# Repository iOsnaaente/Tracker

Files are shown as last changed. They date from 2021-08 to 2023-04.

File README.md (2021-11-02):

# Tracker
Criação de um supervisório para controle de movimentação de um gerador solar do tipo rastreador do sol - Tracker

# Requerimentos
pip install -r requirements.txt

# Dear PyGui 
Software criado sobre a GUI DearPygui - https://github.com/hoffstadt/DearPyGui

# Log 

Protótipo de criação de um rastreador solar - Tracker
    
    Firmware utilizado em um Raspberry pi Pico para controle
    de motores de passo que realizam o rastreamento solar
    garantindo mais geração elétrica a partir de painéis
    fotovoltáicos.

    Versão 0.9.2::
        >>> Código AS5043A para encoder Magnético
        >>> Nova tentativa de rastreamento da posição dos motores

    Versão 0.9.1::
        >>> Processamento dos dados do acelerometro
        >>> Valores obtidos inconclusivos para a finalidade
        >>> Acelerometro não será usado 
    
    Versão 0.9.0::
        >>> Criação do arquivo Acell.py para os dados do acelerometro
        >>> Teste do acelerometro
        >>> Criação das funções de acionamento dos motores via relé 

    Versão 0.8.1::
        >>> Adaptação da placa de desenvolvimento::
            >>> Acrescimo do relé de acionamento dos motores 
    
    Versão 0.8.0::
        >>> Correção da comunicação serial.
        >>> Criação de mais variáveis de estado
        
    Versão  0.7.0::
        >>> Criação do módulo Timanager. Junção de Timer e Manager
            Realiza todo controle de passagem de tempo e movimento
            decorrente desse periodo.
    
    Versão 0.6.1::
        >>> Correção do movimento de retorno do Tracker.
            >>>Segundo teste de fogo::
                >>> Controle de retorno OK
                
    Versão 0.6.0::
        >>> Movimentação acelerada do movimento real de rastreio.
            >>>Primeiro teste de fogo::
                >>> Movimentação OK 
                >>> Dados precisos OK
                >>> Controle de retorno FAIL
    
    Versão 0.55.0::
        >>> Extinção do uso de threads para os Levers.
        >>> Extinção do uso de threads para a Serial.
        
    Versão  0.5.0::
        >>> Levers. Criação da Classe Levers para controle manual dos
            motores via alavancas presas à placa de desenvolvimento.
            Evitando poluição de código.
            
    Versão  0.4.0::
        >>> Const. Evitando poluição do escopo principal (main),
            separou-se as constantes em outro file.py chamado Const
        >>> FileStatements. Criação de um file.py FileStatements
            que guarda as funções de escrita Flash do RasPico.
            
    Versão  0.3.0::
        >>> Serial comunication. Ponta pé inicial da comunicação serial
            utilizando structs pack e unpack. Funcional, mas incompleto.
            
    Versão  0.23.0::
        >>> Finalização da Classe StepMotors. Adição dos nanoSteps que
            guardam decimais do movimento dos motores.
            StepMotors agora esta mais organizado e limpo.
            Funcionando 100% porém falta documentar.
        >>> Criação da função get_twilights() dentro de SunPosition.
            Função responsável por pegar os horários de crepusculos do dia.
            
    Versão  0.21.0::
        >>> Correção da classe StepMotors. Separação da classe Motors
            em duas classes distintas. Motors e Motor ( pai e filho).
        >>> Correção no código do DS3231.
        >>> Documentação do código do DS3231. Agora esta 100%.
        
    Versão  0.2.0::
        >>> Criação da interface StepMotors para fazer o controle dos
            motores de passo.
        >>> Criação da interface DS3231. Faltam ajustes.
        >>> Finalização do código SunPosition de rastreio solar. Já funciona.
        
    Versão  0.1.0::
        >>> Correções no código SunPosition de rastreio solar. Definição
            final de como será feito a computação das posições de azimute
            e zenite( altitude ) sem o uso de classes.
            >>> Função Compute() realiza todos os cálculos.
            
    Versão 0.01.0::
        >>> Estruturação do primeiro modelo funcional.
        >>> Definição de todo o escopo do Firmware.
            >>> Rastreio solar - SunPosition
            >>> Contagem da hora - DS3231
            >>> Controle dos motores - StepMotors
            
    Versão 0.0.10::
        >>> Migração do código em C ( Arduino ) para Python 
     
"""

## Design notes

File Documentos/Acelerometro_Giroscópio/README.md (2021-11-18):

# Sensor Magnetômetro 3 Eixos - GY-271

O Sensor Magnetômetro 3 Eixos Gy-271 mede o campo magnético e funciona como uma Bússola Digital, podendo ser usado por exemplo com o Arduino para indicar o norte geográfico da Terra.

[b] Durante um periodo de 24h a bussola gira 360º em sentido norte, provando que a Terra gira em um periodo de aproximadamente 24h :D 

Sensor adquirido em https://www.eletrogate.com/sensor-magnetometro-3-eixos-gy-271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 

Protocolo de comunicação I2C 

Necessita da biblioteca QMC5883LCompass anexa em ./utils
Criada por [MPrograms](https://github.com/mprograms/QMC5883LCompass/) Página git do projeto [Github Project Page](https://github.com/mprograms/QMC5883LCompass/)

Para mais informações ler o README da biblioteca anexa 

## Ploter.py 
O repositório GY-271 com os códigos arduino possuem também um arquivo Ploter.py que nada mais é do que um plotador dos dados recebidos via Serial. 

Para rodar o ploter, há a necessidade de se ter instala a biblioteca DearPyGui na sua versão 0.8.4 disponível em requirements.txt 

# MMA845x

Sensor adquirido em https://www.baudaeletronica.com.br/acelerometro-3-eixos-mma8452.html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

Protocolo de comunicação I2C 

Necessita da biblioteca SFE_MMA8452Q anexa em ./utils
Biblioteca criada por: [MPrograms](Jim Lindblom @ SparkFun Electronics) 
Disponível em: [Github Project Page](https://github.com/sparkfun/MMA8452_Accelerometer)

## Ploter.py 
O repositório GY-271 com os códigos arduino possuem também um arquivo Ploter.py que nada mais é do que um plotador dos dados recebidos via Serial. 

Para rodar o ploter, há a necessidade de se ter instala a biblioteca DearPyGui na sua versão 0.8.4 disponível em requirements.txt

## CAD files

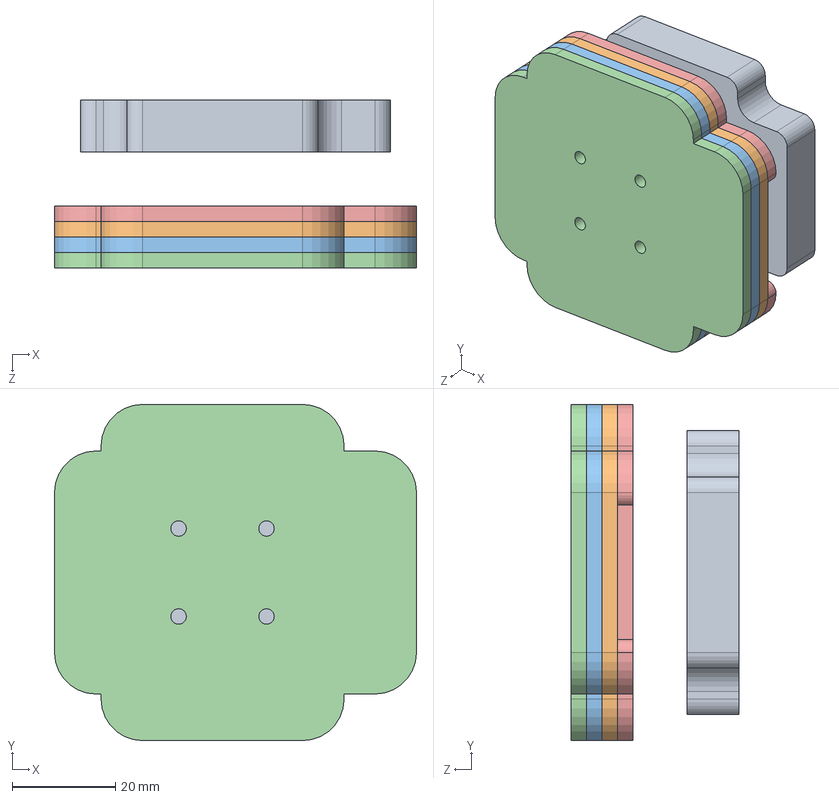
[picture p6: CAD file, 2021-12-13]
3D/SuporteSensor/Montagem3.SLDASM
70.0 x 65.0 x 32.4 mm
Braçadeira1
Base_sensor^Montagem3
Base
BraçadeiraFios
CentralizadorImã

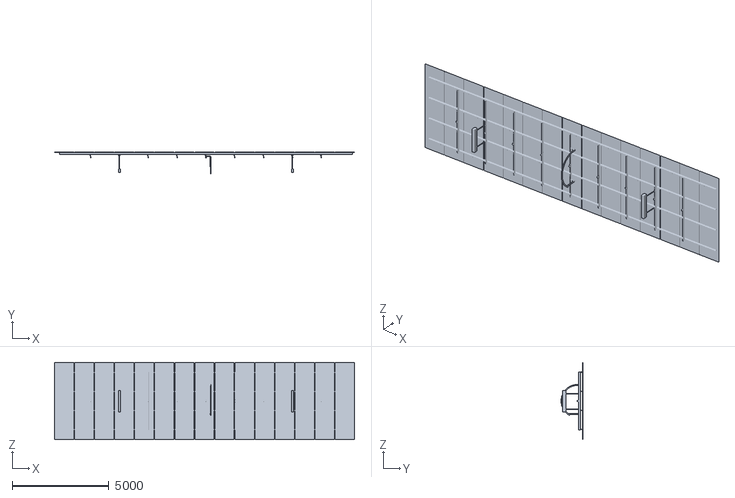
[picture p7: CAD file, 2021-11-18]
3D/Elevação.STL
15500.0 x 1131.9 x 4000.0

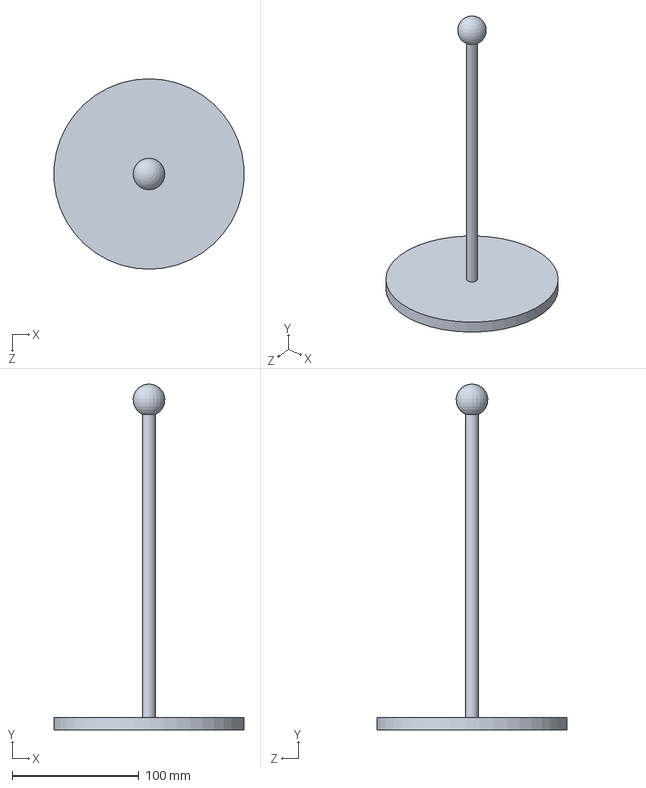
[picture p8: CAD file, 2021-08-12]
3D/models/GIR_PAINEL.SLDPRT
149.6 x 272.5 x 150.0 mm

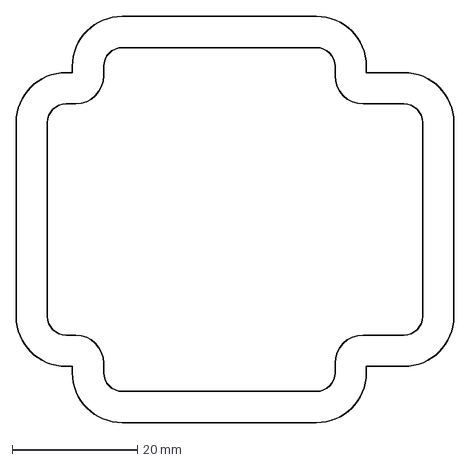
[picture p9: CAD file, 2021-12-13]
3D/SuporteSensor/Braçadeira_x2.DXF
70.0 x 65.0 mm

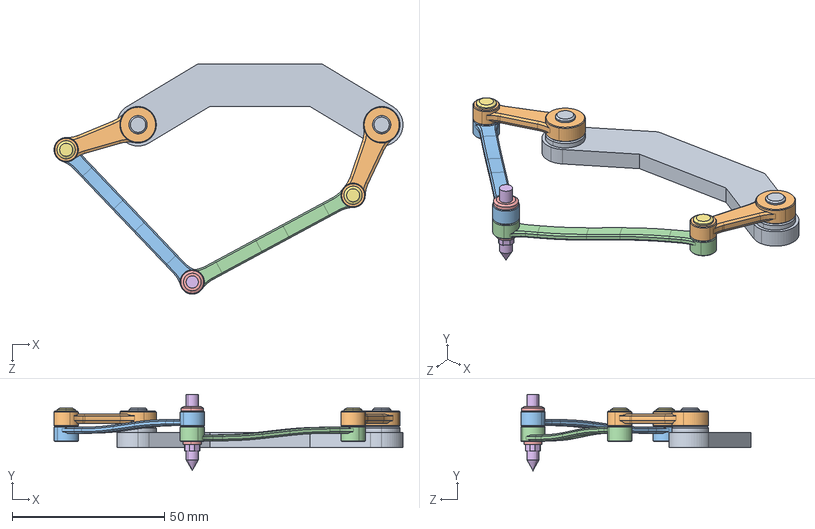
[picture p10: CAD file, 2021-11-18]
Interface/utils/ico/5 Linkages Mechanism.STEP
114.6 x 25.0 x 75.6 mm
Base
Link-01 x 2
Link-02
Link-02_Reverse
Connector
Pen
Pin x 2

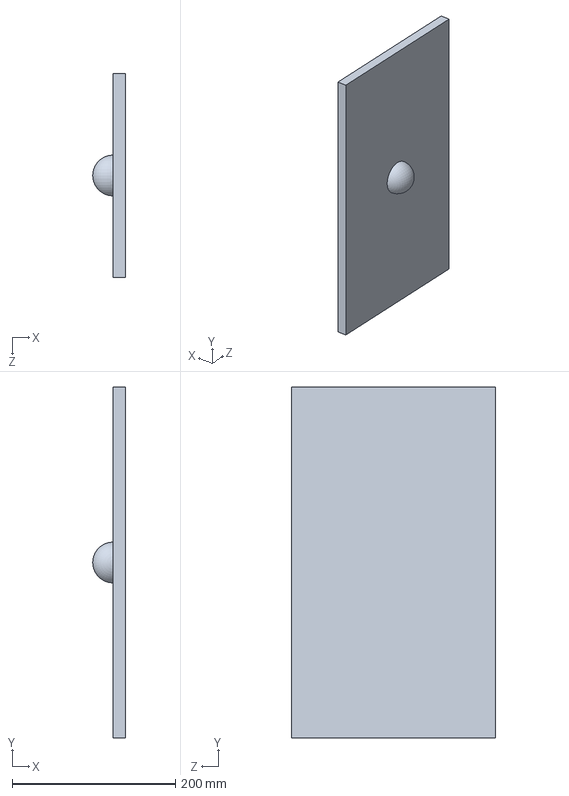
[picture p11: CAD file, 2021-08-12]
3D/models/ELE_PAINEL.SLDPRT
40.0 x 430.0 x 250.0 mm

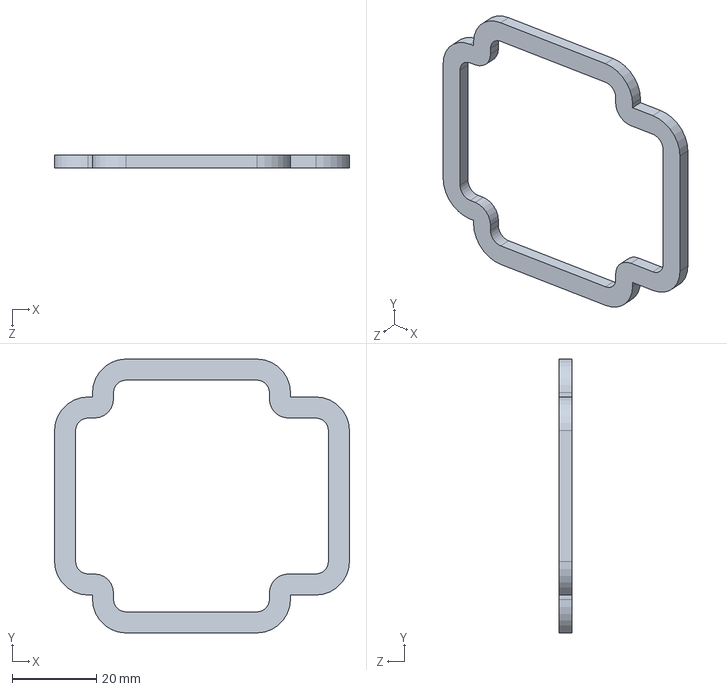
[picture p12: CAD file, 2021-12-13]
3D/SuporteSensor/Braçadeira1.sldprt
70.0 x 65.0 x 3.00 mm

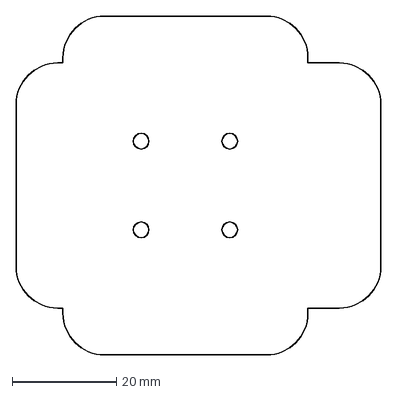
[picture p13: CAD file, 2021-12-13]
3D/SuporteSensor/Base_x2.DXF
70.0 x 65.0 mm

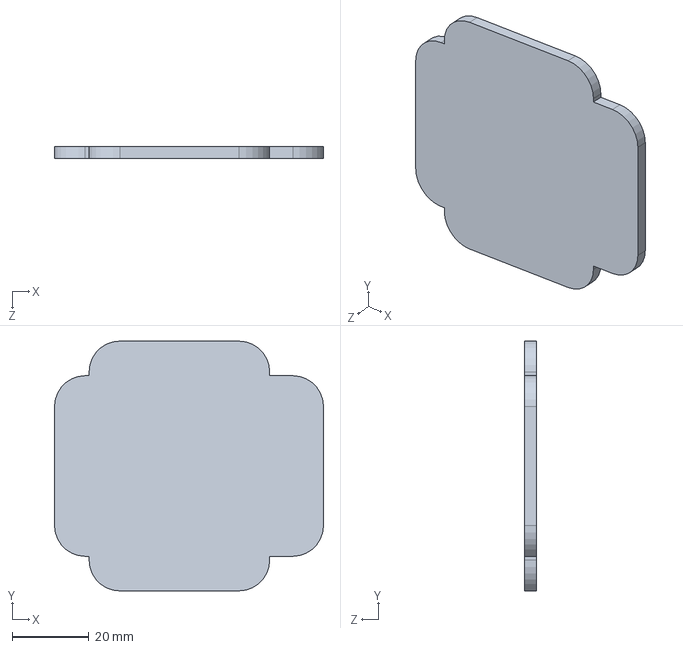
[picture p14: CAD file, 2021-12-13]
3D/SuporteSensor/Base.sldprt
70.0 x 65.0 x 3.00 mm

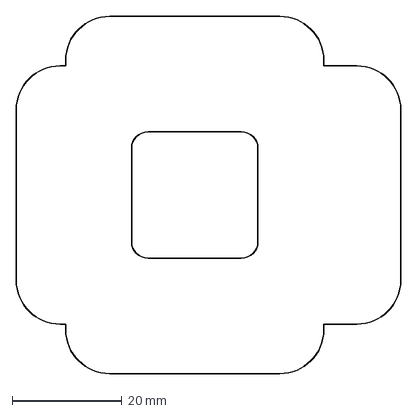
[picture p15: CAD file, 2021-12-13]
3D/SuporteSensor/BaseSensor_x2.DXF
70.0 x 65.0 mm

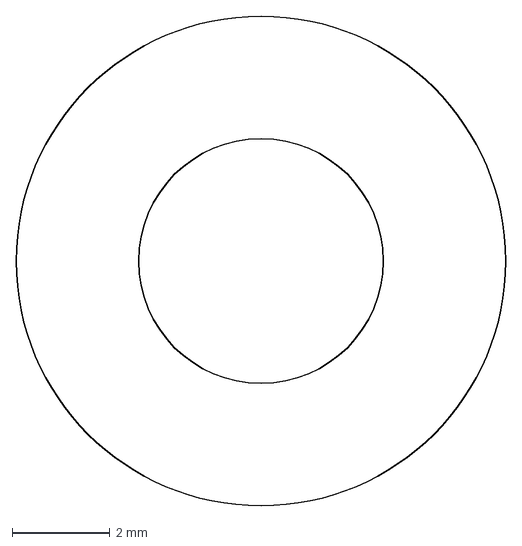
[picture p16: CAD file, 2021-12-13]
3D/SuporteSensor/CentralizadorImã_x3.DXF
10.0 x 10.0 mm

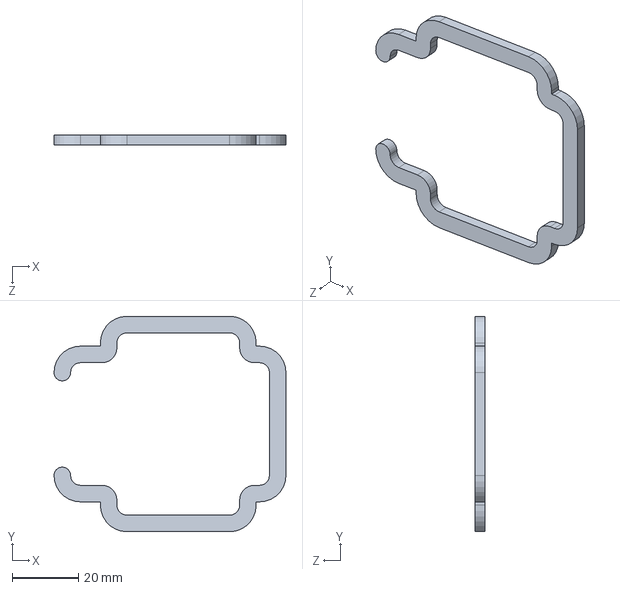
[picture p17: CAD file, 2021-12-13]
3D/SuporteSensor/BraçadeiraFios.sldprt
70.0 x 65.0 x 3.00 mm

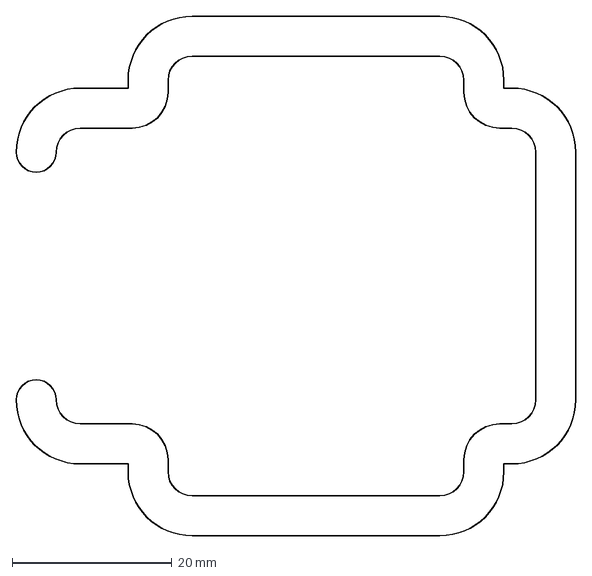
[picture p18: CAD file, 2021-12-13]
3D/SuporteSensor/BraçadeiraFios_x2.DXF
70.0 x 65.0 mm

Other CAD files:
3D/SuporteSensor/Tampa_Top.sldprt
3D/SuporteSensor/CentralizadorImã.sldprt
3D/SuporteSensor/Corpo_Body.sldprt
3D/SuporteSensor/Tampa_Button.sldprt
3D/models/ELE_PAINEL.STL
3D/models/ELE_PAINEL.obj
3D/models/GIR_PAINEL.STL
3D/models/GIR_PAINEL.obj

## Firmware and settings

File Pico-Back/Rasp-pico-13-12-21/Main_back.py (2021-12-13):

#!/usr/bin/env python
# -*- coding: utf-8 -*-

from machine        import Pin, I2C

from Levers         import Lever_control
from Timanager      import Timemanager 
from StepMotors     import Motors
from DS3231         import DS3231
from Acell          import *
from SunPosition    import *
from FileStatements import *
from Const          import * 

import select 
import struct 
import time 
import sys
import gc

# INSTANCIAMENTO DOS PERIFÉRICOS 
MOTORS = Motors( STEP_GIR, DIR_GIR, STEP_ELE, DIR_ELE, ENABLE_MTS )
MOTORS.configure( MOTORS.GIR, pos = 0.0, step = 1.8, micro_step = 8, ratio = 1 )
MOTORS.configure( MOTORS.ELE, pos = 0.0, step = 1.8, micro_step = 8, ratio = 1 )
MOTORS.set_torque( True )

# Ativa os motores 
POWER_MOTORS_STATE = HIGH  
POWER_MOTORS = Pin( POWER, Pin.OUT )  
POWER_MOTORS.value( POWER_MOTORS_STATE ) 

LED_POWER = Pin(LED1_RED , Pin.OUT)

def turn_off_motors():
    POWER_MOTORS_STATE = LOW
    POWER_MOTORS.low( )
    LED_POWER.low( ) 
    
def turn_on_motors():
    POWER_MOTORS_STATE = HIGH
    POWER_MOTORS.high( )
    LED_POWER.high( ) 
    

# BOTÕES / ALAVANCAS PARA MOVER OS MOTORES
LEVERS = Lever_control( lever_pins_A = [BUTTON_GP,BUTTON_GM], lever_pins_B = [BUTTON_EP,BUTTON_EM], LED = [LED1_RED, LED1_BLUE]  )


# LEDS E LED BUILTIN DA PLACA PICO 
LED2_RED    = Pin(LED2_RED , Pin.OUT)
LED2_BLUE   = Pin(LED2_BLUE, Pin.OUT)
LED_BUILTIN = Pin( LED_BUILTIN, Pin.OUT ) 


# SERIAL CONFIGURAÇÕES 
BYTE_INIT = [b'I',b'N',b'I',b'T']  
count     = 0

# PINOS DO DS3231 
DS  = DS3231( 0, Pin( SDA_DS ), Pin( SCL_DS ), addrs = [0x68, 0x57] )

try:
    #MAG = QMC5883L( i2c_bus = I2C(1, Pin(18,Pin.OUT), Pin(19, Pin.OUT)), address=DFLT_ADDRESS, output_data_rate=ODR_200HZ, output_range=RNG_8G, oversampling_rate=OSR_512 ) 
    mag = I2C(1, sda=Pin(18,Pin.OUT), scl=Pin(19, Pin.OUT), freq = 100_000)
    print( mag, mag.scan() )
    a = mag.readfrom_mem( 13, 0x00, 2 )
    print( a ) 
    MAG = QMC5883L( mag ) 
except: 
    print("MAG not connected")

# CONTROLE DOS ANGULOS DO SOL 
timanager = Timemanager( DS, MOTORS )

# Garbage Collector Enable 
gc.enable()


# SETAR A HORA DO DS3231 
#DS.set_time( 21, 10, 21, 16, 47, 20  )


# ESTADO DE INICIALIZAÇÃO
STATE = WAKE_UP

autoEngine = True 
time_delay = 1 
count_mov  = 0 
last_time  = time.time() 

LIMIT = 50 
DATA_TRAIN = [] 

while True:
    # INICIALIZAÇÃO
    if STATE == WAKE_UP:
        print( "BOM DIA!!!") 
        
        #TIME = timanager.up_fake_time( up = True )
        TIME = DS.now() 
        
        timanager.start( TIME )
        
        STATE = AUTOMATIC_TRACKING
        
        if autoEngine: 
            turn_on_motors() 
        else:
            turn_off_motors()

    elif STATE == GET_DATA:
        LED_BUILTIN.toggle()
        levers_state = LEVERS.check_levers()
        if any(levers_state):
            if   levers_state[0]: timanager.move(  1,  0 )
            elif levers_state[1]: timanager.move( -1,  0 )
            if   levers_state[2]: timanager.move(  0,  1 )
            elif levers_state[3]: timanager.move(  0, -1 ) 
            count_mov += 1
            
            try:
                x,y,z = MAG.get_magnet_raw()
            except:
                print( 'Error. magnetico fora ')
                x,y,z = 0,0,0
                
            DATA = struct.pack('ffffff',count_mov,timanager.MOTORS.GIR_POS, timanager.MOTORS.ELE_POS, x, y, z) 
            DATA_TRAIN.append( DATA )
            
            if count_mov > 0:       
                with open('reg.txt', 'a') as f : 
                    f.write( b'{},\n'.format(DATA_TRAIN) )
                DATA_TRAIN = [] 


    # RASTREADOR 
    elif STATE == AUTOMATIC_TRACKING:
        #TIME = timanager.up_fake_time( )
        TIME = DS.now() 
        timanager.update( TIME )
        
        if timanager.get_altitude() > 0:
            LED2_BLUE.high()
            LED2_RED.low()            
        else:
            LED2_BLUE.low()
            LED2_RED.high()
            STATE = AUTOMATIC_BACKWARD 
    

    # RETORNO PARA O PONTO INICIAL DO DIA SEGUINTE 
    elif STATE == AUTOMATIC_BACKWARD:
        TIME[2] += 1
        if TIME[1] == 2: 
            if ANB(TIME[0]) :  DOM[1] = 29 
            else:              DOM[1] = 28 
        if TIME[2] > DOM[TIME[1]]:
            TIME[1] += 1
            TIME[2] = 1 
            if TIME[1] > 12: 
                TIME[0] += 1
                TIME[1] = 1 
            
        timanager.update( TIME )

        STATE = AUTOMATIC_SLEEPING
        continue 
    

    # ESPERA O NOVO DIA NASCER 
    elif STATE == AUTOMATIC_SLEEPING:
        TIME = DS.now() 
        if timanager.check_alt( TIME ):
            STATE = AUTOMATIC_TRACKING

    # INICIA O MODO DE OPEÇÃO ACELERADO ( DEMONSTRAÇÃO )
    elif STATE == MANUAL_DEMO:
        TIME = timanager.up_fake_time( up = True )
        timanager.update( TIME )
        timanager.print() 
    
    
    # CONTROLE MANUAL ATRAVÉS DOS LEVERS
    elif STATE == MANUAL_CONTROLING:
        levers_state = LEVERS.check_levers()
        if any(levers_state):
            if   levers_state[0]: timanager.move(  1,  0 )
            elif levers_state[1]: timanager.move( -1,  0 )
            if   levers_state[2]: timanager.move(  0,  1 )
            elif levers_state[3]: timanager.move(  0, -1 ) 
    

    # PARA O TRACKER
    elif STATE == MANUAL_STOPING:
        pass


    # VERIFICA SE RECEBEU ALGO DA SERIAL 
    while sys.stdin in select.select( [sys.stdin], [sys.stdout], [sys.stderr], 0 )[0]:  
        cmd = sys.stdin.buffer.read(1)
        if cmd == BYTE_INIT[count]:  count += 1
        else:                        count  = 0
 
        if count == 4:
            count = 0
            BYTE_ID  = sys.stdin.buffer.read(1)
            LED_BUILTIN.toggle()
            

            '''
            H -> Troca a hora
            M -> Move ambos motores
            m -> Move um dos motores
            S -> Para o tracker ( muda o estado )
            D -> Entra no modo Demo ( Demontração )
            C -> Para continuar o processo ( muda o estado ) 
            R -> Retorna para o inicio do dia
            O -> Muda para ativado os motores
            F -> Muda para desativado os motores 
            G -> Get data to conv net
            A -> Acelerometro medidas 
            '''
            
            
            if   BYTE_ID == b'H':
                confirm = sys.stdin.buffer.read(1)
                if confirm == b'O':
                    print('Recebido: {} para trocar a hora'.format(BYTE_ID))
                    year, month , day    = sys.stdin.buffer.read(3)
                    hour, minute, second = sys.stdin.buffer.read(3)
                    DS.set_time( year, month, day, hour, minute, second )
            
            
            elif BYTE_ID == b'M':
                confirm = sys.stdin.buffer.read(1)
                if confirm == b'O':
                    print('Recebido: {} para mover os dois motores'.format(BYTE_ID))
                    posG = struct.unpack( 'f', sys.stdin.buffer.read(4) )
                    posE = struct.unpack( 'f', sys.stdin.buffer.read(4) )
                    print(posG, posE, type(posG), type(posE))
                    timanager.move_to( POS = [ posG, posE ] )
                
                
            elif BYTE_ID == b'm':
                confirm = sys.stdin.buffer.read(1)
                if confirm == b'O':
                    print('Recebido: {} para mover somente um motor'.format(BYTE_ID))
                    motor_id = sys.stdin.buffer.read(1)
                    if motor_id == b'E':
                        posE = struct.unpack( 'f', sys.stdin.buffer.read(4) )
                        posG = [ float(s2f) for s2f in file_readlines( FILE_PATH, FILE_READ ) ][0]
                        timanager.move_to( POS = [ posG, posE ] )
                        print('POS E:', posE,' POS G:', posG, ' TYPE E:', type(posE),' TYPE G:',type(posG))

                    if motor_id == b'G':
                        posG = struct.unpack( 'f', sys.stdin.buffer.read(4) )
                        posE = [ float(s2f) for s2f in file_readlines( FILE_PATH, FILE_READ ) ][1]
                        timanager.move_to( POS = [ posG, posE ] )
                        print('POS E:', posE,' POS G:', posG, ' TYPE E:', type(posE),' TYPE G:',type(posG))
            
            
            elif BYTE_ID == b'S':
                confirm = sys.stdin.buffer.read(1)
                if confirm == b'O':
                    print('Recebido: {} para parar o processo'.format( BYTE_ID))
                    STATE = MANUAL_STOPING
            

            elif BYTE_ID == b'D':
                confirm = sys.stdin.buffer.read(1)
                if confirm == b'O':
                    print('Recebido: {} para iniciar o modo de demonstração do processo'.format( BYTE_ID))
                    STATE = MANUAL_DEMO
                    TIME = DS.now() 
                    timanager.update(TIME)
                    time_delay = 1 
            
            
            elif BYTE_ID == b'C':
                confirm = sys.stdin.buffer.read(1)
                if confirm == b'O':
                    print('Recebido: {} para continuar o processo'.format( BYTE_ID))
                    STATE = AUTOMATIC_TRACKING
                    timanager.update(TIME)
                    time_delay = 1 
                
                
            elif BYTE_ID == b'R':
                confirm = sys.stdin.buffer.read(1)
                if confirm == b'O':
                    print('Recebido: {} para retornar ao inicio do dia'.format( BYTE_ID))
                    TIME = DS.now()
                    TIME[3:6] = [0,0,0]
                    timanager.update(TIME)
            
            
            elif BYTE_ID == b'W':
                confirm = sys.stdin.buffer.read(1)
                if confirm == b'O':
                    print('Hello Tracker!!'.encode() )
            
            
            elif BYTE_ID == b'P':
                confirm = sys.stdin.buffer.read(1)
                if confirm == b'O':
                    timanager.print()
            
            elif BYTE_ID == b'O':
                confirm = sys.stdin.buffer.read(1)
                if confirm ==  b'O':
                    sys.stdout.write("Turn on the power motors".encode())
                    turn_on_motors()
            
            elif BYTE_ID == b'F':
                confirm = sys.stdin.buffer.read(1)
                if confirm == b'O':
                    sys.stdout.write("Turn off the power motors".encode())
                    turn_off_motors()
            
            elif BYTE_ID == b'G':
                confirm = sys.stdin.buffer.read(1)
                if confirm == b'O':
                    print('Aquisição de dados')
                    STATE = GET_DATA 
                    time_delay = 0.001
                    last_time = time.time()
                    count_mov = 0
            
            elif BYTE_ID == b'A':
                confirm = sys.stdin.buffer.read(1)
                if confirm == b'O':
                    try: 
                        print( MAG.get_magnet_raw() )
                    except:
                        try:
                            print( 'Magnetic sensor error: {}'.format(MAG.scan() ) )  
                        except:
                            print("Magnetic sensor not conected")
    #timanager.print()
    time.sleep(time_delay)
    
    # GARBAGE COLLECTOR 
    #gc.collect()

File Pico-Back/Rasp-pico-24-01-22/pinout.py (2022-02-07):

# VARIÁVEIS USADAS NAS GPIOs DO RASPICO 
STEP_GIR    = 0 
STEP_ELE    = 1 
STEP_GEN    = 2

DIR_GIR     = 3
DIR_ELE     = 4
DIR_GEN     = 5 

BUTTON_GP   = 6 
BUTTON_GM   = 7

BUTTON_EP   = 8
BUTTON_EM   = 9

LED1_RED    = 10
LED1_BLUE   = 11
LED2_RED    = 12
LED2_BLUE   = 13

ENABLE_MTS  = 14

POWER       = 15

SDA_DS      = 16 
SCL_DS      = 17
 
SDA_AS      = 18
SCL_AS      = 19 

UART_TX     = 20 
UART_RX     = 21

LED_BUILTIN = 25

# DATA E HORA 
UTC = -3 
DOM = [ 31, 28, 31, 30, 31, 30, 31, 31, 30, 31, 30, 31]
ANB = lambda year : True if (year%100 != 0 and year%4 == 0) or (year%100 == 0 and year%400 == 0) else False

# CONFIGURAÇÕES DE RASTREAMENTO 
LATITUDE    = -29.16530765942215
LONGITUDE   = -54.89831672609559 
TEMPERATURE =  298.5
PRESSURE    =  101.0

LOCALIZATION = [ LATITUDE, LONGITUDE, TEMPERATURE, PRESSURE ]


AUTOMATIC = 1
MANUAL    = 2
REMOTE    = 3
DEMO      = 4
IDLE      = 5

# MACRODEFINIÇÕES 
AUTOMATIC_SLEEPING =  3   # Dormindo esperando um novo dia começar 
AUTOMATIC_BACKWARD =  2   # Retorna para a posição inicial do novo dia
AUTOMATIC_TRACKING =  1   # Rastreia o sol em um dia normal 
WAKE_UP            =  0   # Opção de inicio. É chamado quando o Rasp liga
MANUAL_CONTROLING  = -1   # Ativa o controle por Levers 
MANUAL_STOPING     = -2   # Para o rastreio do tracker
MANUAL_DEMO        = -3   # Segue o sol de forma acelerada ( Demonstração ) 
GET_DATA           =  99 

LOW = 0
HIGH = 1 

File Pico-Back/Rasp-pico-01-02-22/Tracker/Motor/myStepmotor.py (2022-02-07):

from machine import Pin
from time    import sleep_ms
from rp2     import StateMachine 
from rp2     import asm_pio 
from rp2     import PIO

BACKWARD = False
FORWARD  = True

DISABLE = 1 
ENABLE  = 0

@asm_pio( set_init = PIO.OUT_LOW )
def move():
    label('init')
    pull( )
    mov( x, osr )
    label( 'step_m1' )
    set(pins, 1)             
    set(pins, 0)            
    jmp( x_dec, 'step_m1')  
    jmp( 'init' )

class Motor: 
    direction = FORWARD
    torque    = ENABLE
    position  = 0.0 
    ratio     = 1.0 
    step      = 1.8
    u_step    = 16 
    nano_step = 0.0
    name      = '' 

    # Para ter 30rpm durante 1 segundo
    rpm       = 0 
    pps       = 800  

    def __init__(self, STEP_PIN : int, DIRECTION_PIN : int, ENABLE_PIN : int, TORQUE : bool = False, FREQ : int = 2000, NUM_SM : int = 1 ) -> None:
        self.STEP_PIN       = Pin( STEP_PIN     , Pin.OUT ) 
        self.DIRECTION_PIN  = Pin( DIRECTION_PIN, Pin.OUT )
        self.ENABLE_PIN     = Pin( ENABLE_PIN   , Pin.OUT )

        self.direction      = FORWARD
        self.torque         = ENABLE if TORQUE else DISABLE 
        self.ENABLE_PIN.value( self.torque )

        self.NUM_SM = NUM_SM
        self.FREQ = FREQ 

        self.step   = 1.8
        self.u_step = 8 
        self.ratio  = 1

        self.sm = StateMachine( self.NUM_SM , move, freq = self.FREQ, set_base= self.STEP_PIN )
        
    def activate( self ):
        self.sm.active(1)

    def deactivate(self):
        self.sm.active(0) 

    def configure(self, step : float = 1.8, u_step : int = 8, ratio : float = 1) -> None: 
        self.step   = step
        self.u_step = u_step 
        self.ratio  = ratio 

    def set_torque( self, torque : bool = ENABLE ) -> None:
        self.torque = ENABLE if torque else DISABLE 
        self.ENABLE_PIN.value( self.torque )
    
    def set_name(self, name):
        self.name = name 

    def set_velocity( self, rpm : int = 1 ) -> None:
        self.pps = int( ( rpm * 360 * ( self.u_step // self.step ) )/( 60 * self.step ))
        self.rpm = rpm 
    
    def set_direction( self, direction : bool ) -> None:
        self.direction = FORWARD if direction else BACKWARD
        self.DIRECTION_PIN.value( 1 if self.direction == FORWARD else 0 ) 
    
    #def _pulse(self, time_spend : int = 2 ) -> None :
    #    self.STEP_PIN.high()
    #    sleep_ms ( time_spend//2 )
    #    self.STEP_PIN.low()
    #    sleep_ms ( time_spend//2 )
    
    def move( self, n_pulses : int, time_stemp : int = 10 ) -> None:  
        if self.torque != DISABLE:
            self.sm.put( n_pulses )
            if self.direction: self.position += self.step / (self.u_step * self.ratio)  
            else:              self.position -= self.step / (self.u_step * self.ratio)
            if   self.position > 360.0: self.position -= 360.0
            elif self.position < 0:     self.position = 360 - self.position 

    def get_num_pulses(self, angle : int) -> int:
        n_pulso = ((angle*self.u_step)/self.step)*self.ratio
        self.nano_step += n_pulso % 1
        n_pulso = int( n_pulso // 1 )
        
        if self.nano_step > 1.0 :
            self.nano_step -= 1  
            n_pulso += 1
        
        return n_pulso

class Motors:
    GIR_POS = 0
    ELE_POS = 0
    POWER   = 0  

    def __init__(self, gir_stp : [Pin, int], gir_dir : Pin, ele_stp : Pin, ele_dir : Pin, enb_motors : Pin, pin_power : Pin ):
        self.GIR = Motor ( gir_stp, gir_dir, enb_motors, NUM_SM = 0 )
        self.GIR.set_name("Gir/Azimute")
        self.ELE = Motor ( ele_stp, ele_dir, enb_motors, NUM_SM = 1 )
        self.ELE.set_name("Ele/Altitude" )
        self.POWER = Pin( pin_power, Pin.OUT ) 
    
    
    def configure(self, MOTOR : Motor, pos : float, step : float, micro_step : int, ratio : float ) -> None:
        MOTOR.u_step = micro_step 
        MOTOR.ratio  = ratio
        MOTOR.step   = step 
        MOTOR.pos    = pos
        MOTOR.activate()


    def set_torque(self, state : bool ) -> None :  
        self.GIR.torque = ENABLE if state else DISABLE
        self.GIR.ENABLE_PIN.value( self.GIR.torque )
        self.ELE.torque = ENABLE if state else DISABLE
        self.ELE.ENABLE_PIN.value( self.GIR.torque )
        self.POWER.value( state )


    def get_positions(self):
        return [ self.GIR.position, self.ELE.position ]


    def move(self, g_ang : int, e_ang : int, time_stemp : int = 2 ) -> None :
        if   g_ang < 0:   self.GIR.set_direction( BACKWARD   )
        elif g_ang > 0:   self.GIR.set_direction( FORWARD    )

        if   e_ang < 0:   self.ELE.set_direction( BACKWARD   ) 
        elif e_ang > 0:   self.ELE.set_direction( FORWARD    )
        
        g_ang = self.GIR.get_num_pulses( abs(g_ang) )
        e_ang = self.ELE.get_num_pulses( abs(e_ang) )
        if g_ang > 0: 
            self.GIR.move( g_ang )
        if e_ang > 0:
            self.ELE.move( e_ang )

        self.GIR_POS, self.ELE_POS = self.get_positions()

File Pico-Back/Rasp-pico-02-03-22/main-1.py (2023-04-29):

# importações de repositórios locais
from   Tracker.Time.Timanager       import FAKE_TIME

import Tracker.Files.fileStatements as fs 
import Tracker.Sun.mySunposition    as sun 
import Tracker.Motor.myStepmotor    as stp
import Tracker.Time.myDS3231        as ds
import Tracker.Sensor.myAS5600      as sn
import Tracker.Serial.myUART        as sr
import Tracker.Serial.myRegisters   as rg
import Tracker.Serial.myModbus      as mmb
import Tracker.Controle.myPID       as mp
import Tracker.Manual.myLevers      as ml

from constants import * 
from pinout    import *


# importação de repositórios padrões do sistema PICO 
import machine 
import struct 
import time 


# Flags e variáveis globais
led_print     = machine.Pin( LED2_BLUE, machine.Pin.OUT)
STATE         = AUTOMATIC 
MSG           = ""
raise_timmer  = True
wait_new_day  = False
send_datetime = False
print_timmer  = machine.Timer() 


# Inicio da criação do objeto motores. Responsável pelo controle 
# de posição dos motores e controle automático quando os sensores
# falharem, por isso, as configurações de STEP, uSTEP e Ratio devem
# ser configuradas de acordo para evitar problemas de FAIL STATE 
Motors = stp.Motors( STEP_GIR, DIR_GIR, STEP_ELE, DIR_ELE, ENABLE_MTS, POWER )
Motors.configure( Motors.GIR, pos = 0.0, step = 1.8, micro_step = 8, ratio = 1 )
Motors.configure( Motors.ELE, pos = 0.0, step = 1.8, micro_step = 8, ratio = 1 )
Motors.set_torque( False )


# Criação dos barramentos i2c usados para os sensores AS5600 e DS3231 
isc0   = machine.I2C ( 0, freq = 100000, sda = machine.Pin( SDA_DS  ), scl = machine.Pin( SCL_DS  ) ) 
isc1   = machine.I2C ( 1, freq = 100000, sda = machine.Pin( SDA_AS  ), scl = machine.Pin( SCL_AS  ) )
print( isc0, isc0.scan(), '\n', isc1, isc1.scan() ) 


# Criação do objeto TIME que esta atrelado ao relógio RTC
# Responsável pela administração do tempo e temporizadores 
# de alarmes para Wake-up 
try: 
    Time = ds.DS3231( isc0  )
    TIME, TIME_STATUS = Time.get_time() 
    fake_time         = FAKE_TIME( LOCALIZATION, TIME )
    levers            = ml.Lever_control( [BUTTON_GP, BUTTON_GM], [BUTTON_EP, BUTTON_EM], [LED1_RED, LED1_BLUE] )

# Se o DS3231 não estiver de acordo, não tem como o Tracker
# entrar em operação e será obrigado a resetar 
except: 
    machine.soft_reset() 


# Tenta instanciar os sensores de posição DS5600 
# Caso os sensores estejam vivos, seta-se as configurações de 
# incialização ( escrita de 0 nos endereços [0:11] ) 
try: 
    ASGIR  = sn.AS5600  ( isc0 )
    ASELE  = sn.AS5600  ( isc1 )
    ASELE.set_config() 
    STATE = AUTOMATIC 

# Caso os sensores não estejam funcionando, deve-se colocar 
# o Tracker em modo FAIL-STATE 
except:
    print( 'Erro na inicialização do AS5600')
    STATE = FAIL_STATE 


# Tenta inicializar a comunicação via UART
# Geralmente essa parte não causa falhas, porém
# Se o UART não incializar ( Cabos desconectados )
# é interessante o sistema saber para não tentar enviar
# Frames via Serial, evitando erros inesperados.
MODBUS = True

if not MODBUS: 
    print( 'Utilizando modo de comunicação UART:  ')
    Uart   = sr.UART_SUP( 1, 115200, tx  = machine.Pin(UART_TX) , rx  = machine.Pin(UART_RX, machine.Pin.IN) )
    print( Uart.myUART, end = '\n\n' )

else:    
    print( 'Utilizando modo de comunicação Modbus:  ')
    Uart = mmb.myModbusCommunication( 1, 19200, 0x12, tx  = machine.Pin(UART_TX) , rx  = machine.Pin(UART_RX), parity = 'even' )
    
    Uart.set_registers( DISCRETES, COILS, INPUTS, HOLDINGS )
    
    status = Uart.HOLDINGS.set_regs( 0, [1.0, 2.0, 3.0, 4.0, 5.0, 6.0, 7.0, 8.0, 9.0])
    if status is not False:    print( 'Setado os registradores')
    else:                      print( 'Erro ao setar os registradores')
      

# Cada motor possui um PID para correção da posição
# Instanciamento dos PIDs de cada motor
PID_GIR = mp.PID( PV = 100, Kp = 0.75, Kd = 0.51, Ki = 0.5 )
PID_ELE = mp.PID( PV = 100, Kp = 0.75, Kd = 0.51, Ki = 0.5 )

# Atualizaão do angulo para calculo de correção. Há diferenças 
# entre a atualização e computação dos angulos de correção
PID_GIR.att( ASGIR.degAngle() )
PID_ELE.att( ASELE.degAngle() )
   
# QUANDO FOR ESCRITO EM ALGUMA VARIÁVEL DO REGISTRADOR
# SERA NECESSÁRIO SETAR ESSES VALORES NOS REGISTRADORES 
def set_regs():
    global PID_GIR, PID_ELE
    global Uart 
    Uart.HOLDINGS.set_regs( 0, [PID_GIR.PV, PID_GIR.Kp, PID_GIR.Ki, PID_GIR.Kd, PID_ELE.PV, PID_ELE.Kp, PID_ELE.Ki, PID_ELE.Kd, STATE ] )
    global TIME
    Uart.INPUTS.set_regs( 0, TIME[:-1])
    
# AO CONTRARIO, TODA VEZ QUE FOR PRECISO USAR OS VALORES
# DE REGISTRADORES, DEVE-SE PEGAR ESSES VALORES  
def get_regs():
    pass 



def print_func( timmer_obj ):
    global raise_timmer
    global Uart
    global led_print
    led_print(1)
    
    MSG = '{}\n'.format( Time.get_time()) 
    MSG += "Giro:\t\t{}\n".format( ASGIR.degAngle() ) 
    MSG += "PV(GIR):\t{}\n".format( PID_GIR.PV ) 
    MSG += "Error:\t\t{}\n".format( PID_GIR.Error_real )
    MSG += "Kd Ki Kp:\t{} {} {}\n".format( PID_GIR.Kd, PID_GIR.Ki, PID_GIR.Kp )
    MSG += "Elevação:\t{}\n".format( ASELE.degAngle() ) 
    MSG += "PV(ELE):\t{}\n".format( PID_ELE.PV )
    MSG += "Error:\t\t{}\n".format( PID_ELE.Error_real ) 
    MSG += "Kd Ki Kp:\t{} {} {}\n".format( PID_ELE.Kd, PID_ELE.Ki, PID_ELE.Kp )
    print( MSG, Time.get_raw_datetime() )
    Uart.serial_write_data( initH = Time.get_raw_datetime() )
    raise_timmer = True
    
    led_print(0)
  
# Quando um novo dia é detectado ou pela troca de dias no TIME[2] ou pela 
# detecção da Altitude < 0º no quadrante OESTE. Dessa forma o Tracker deve 
# voltar para a posição de Sunrise do novo dia no quadrante LESTE 
def move_new_day():
    # Como o zero (0º) é definido sobre o Norte, para retornar de Leste -> Oeste 
    # O tracker deve percorrer um caminho antihoário L -> N (270º -> 0º ) e um 
    # caminho horário N -> O ( 0º -> 90º ). Por isso são necessárias duas etapas
    # para se fazer a correção da posição de forma correta 
    diff = int(360-AZIMUTE)

    #Gira no sentido antihorário para voltar meio dia 
    for ah in range( diff ):
        PID_GIR.set_PV( AZIMUTE + ah ) 
        measure_gir = ASGIR.degAngle()
        posG = PID_GIR.compute( measure_gir )
        Uart.response( initg = measure_gir, inite = ASELE.degAngle() )
        Motors.move( 0, posG*0.05 )
    
    # Gira no sentido horário para continar voltando mais meio dia 
    for h in range( diff ):
        PID_GIR.set_PV( ah ) 
        measure_gir = ASGIR.degAngle()
        posG = PID_GIR.compute( measure_gir )
        Uart.response( initg = measure_gir, inite = ASELE.degAngle() )
        Motors.move( 0, posG*0.05 )


def save_statements():
    bus0  = '{}{}\n'.format( isc0, isc0.scan() )
    bus1  = '{}{}\n'.format( isc1, isc1.scan() )
    uart  = '{}'.format( Uart.myUART ) 
    date  = 'DATE_TIME = {}'.format( Time.get_time() )
    state = 'STATE = {}'.format(STATE)
    MSG = bus0 + bus1 + uart + date + state
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

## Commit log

2021-05-19 Atualização de dimensão entre views
2021-05-24 Update diario 2 24/05/21
    [CONFIG.txt]
2021-05-25 Update diário 1 25/05/21
    [CONFIG_Backup.txt]
2021-05-25 Update diário 2 25/05/21
    [CONFIG.txt]
2021-05-26 Update diário 1 26/05/21
    [CONFIG_Backup.txt]
2021-06-02 Update diário 1 02/06/21
    [data.csv]
2021-08-12 Update Tracker files - 12/08/21
    [ELE_PAINEL.SLDPRT, ELE_PAINEL.STL, ELE_PAINEL.obj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]
2021-08-12 Aquisiçõ de dados
    [ELE_PAINEL.SLDPRT, ELE_PAINEL.STL, ELE_PAINEL.obj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]
2021-08-26 Modularização das views - Com cara de programa já :D
2021-08-31 Update 31/08/2021 - No edit
    [CONFIG.txt]
2021-09-14 criação web com NextJS para o tracker
2021-10-04 Backup do firmware do rasp para novas atualizações
2021-11-18 Backup 18-11-21
    [5 Linkages Mechanism.STEP, CONFIG.txt, Elevação.STL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]
2021-12-13 Aplicado PID
    [5 Linkages Mechanism.STEP, Base.sldprt, BaseSensor_x2.DXF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]
2022-01-21 atualização 21-01-22
    [5 Linkages Mechanism.STEP, CONFIG.txt]
2022-02-07 update 07-02-22 / 16h41
    [5 Linkages Mechanism.STEP, CONFIG.txt]
2022-02-11 Removido o web-tracker para evitar alertas de vulnerabilidades que não me interessam
    [Elevação.STL]
2023-09-28 Atualização dos módulos
    [5 Linkages Mechanism.STEP, Base.sldprt, BaseSensor_x2.DXF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]
2023-09-28 Add requirements.txt
    [Mensagem_MODBUS.xlsx]
